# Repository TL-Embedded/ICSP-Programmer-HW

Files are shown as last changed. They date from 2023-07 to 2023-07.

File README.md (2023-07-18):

# ICSP-Programmer-HW

This is a ICSP programming board for AVR targets.

The processor onboard is an ATMEGA8A, and can be programmed using another ICSP-Programmer.

# Connector

The connector is laid out as per a standard Arduino ICSP programmer, so this can to program AVR Arduinos via IDC ribbon cable. This can also be combined with a TC2030 cable for a tag connect solution.

The ICSP connector is laid out as follows:

| Function | Pin # | Pin # | Function |
| --- | ----- | ----- | --- |
| MISO | 1 | 2 | VCC |
| SCK | 3 | 4 | MOSI |
| NRST | 5 | 6 | GND |

# Target VCC

The programmer powered via 5V from USB, but does **not** power the target by default. The `VCC` pin is used for voltage reference. The target voltage may be anywhere between 1.8V and 5.5V.

The labeled `VCC` pin can be used to inject voltage to the target. Alternately the jumper `JP1` can be shorted to tie `VCC` to USB 5V.

# USB

The USB C connector operates in USB 2.0 legacy mode. A FTDI `FT230QX` chip provides a serial port interface.

Drivers for the FTDI chip can be found [here](https://ftdichip.com/drivers/).

# Firmware

The firmware for this PCB is [ICSP-FW.hex](./firmware/ICSP-FW.hex).
See the usage section for an example of programming a ICSP programmer from another programmer.

Note: To Program a ICSP programmer, its target `VCC` must *not* be powered. Ensure that `JP1` is open, and no power is provided via the `VCC` pin or ICSP connector.

# Usage

The windows executable version of [avrdude](https://github.com/avrdudes/avrdude) is included in this repo to flash a target.

You will need to substitute your serial port and target information.

An example for flashing the ICSP firmware is below:
```sh
# Verify the target is connected.
.\avrdude.exe -C "avrdude.conf" -c avrisp -P COM3 -b 115200 -p ATMEGA8

# Configure the target fuses.
# This is required to set the oscillator config
.\avrdude.exe -C "avrdude.conf" -c avrisp -P COM3 -b 115200 -p ATMEGA8 -U lfuse:w:0xbe:m -U hfuse:w:0xd9:m

# Flash the target with 'ICSP-FW.hex'
.\avrdude.exe -C "avrdude.conf" -c avrisp -P COM3 -b 115200 -p ATMEGA8 -U flash:w:ICSP-FW.hex:i
```

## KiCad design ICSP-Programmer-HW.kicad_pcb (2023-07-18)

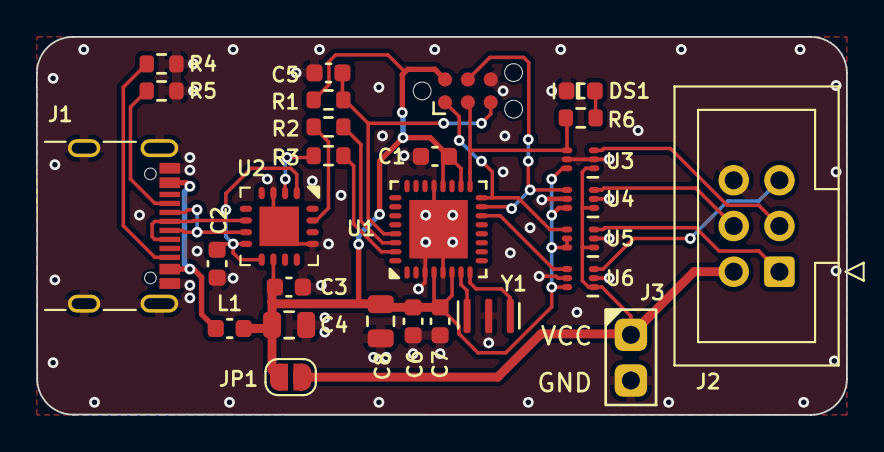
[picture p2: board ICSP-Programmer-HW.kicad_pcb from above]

Board: 2 copper layers, 45.0 x 21.0 mm, 28 parts (0 on the bottom side), 25 nets.

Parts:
C1, C2, C3, C5, C6, C7: 100n; C_0603
C4, C8: 10u; C_0805
DS1: LED_GRN; DS_0603
J1: USB4105-GF-A-060; USB_C_USB4105-GF-A-060
J2: 61200621621; IDC-Header_2x03_P2.54mm_Vertical
J3: Pins_2.54_1x2; Pins-2.54-1x2
JP1: SolderJumper2; SolderJumper-2_P1.3mm_Open_RoundedPad1.0x1.5mm
L1: 600R; FB_0603
N1: TC2030_NL_SWD; TagConnect_TC2030_NL
R1: 10K; R_0603
R2, R3: 1K; R_0603
R4, R5: 5K1; R_0603
R6: 470R; R_0603
U1: ATMEGA8A-MU; QFN32_05_5x5_EP
U2: FT230XQ; QFN16_065_4x4_EP
U3, U4, U5, U6: 74LVC1T45Z6; SOT563
Y1: CSTNE16M0V530000R0; Oscillator_SMD3_3.2x1.3

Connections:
+3.3V: C2.1, U2.1 (VCCIO), U2.8 (3V3OUT), U2.9 (NRST)
+5V: C1.1, C3.1, C4.1, C6.1, C7.1, C8.1, JP1.1 (A), L1.2, N1.2, R1.1, U1.4 (VCC), U1.6 (VCC), U1.18 (AVCC), U1.20 (AREF), U2.10 (VCC), U3.6 (VCCB), U4.6 (VCCB), U5.5 (DIR), U5.6 (VCCB), U6.6 (VCCB)
/MCU/ICSP_MISO: N1.1, U1.16 (PB4/MISO), U5.4 (B)
/MCU/ICSP_MOSI: N1.4, U1.15 (PB3/MOSI), U4.4 (B)
/MCU/ICSP_NRST: C5.1, N1.5, R1.2, U1.29 (NRST/PC5)
/MCU/ICSP_SCK: N1.3, R6.1, U1.17 (SCK/PB5), U3.4 (B)
/MCU/RX: R2.2, U1.30 (RXD/PD0)
/MCU/TARGET_NRST: U1.14 (PB2), U6.4 (B)
/MCU/TX: R3.1, U1.31 (TXD/PD1)
/Target/TARGET_MISO: J2.1, U5.3 (A)
/Target/TARGET_MOSI: J2.4, U4.3 (A)
/Target/TARGET_NRST: J2.5, U6.3 (A)
/Target/TARGET_SCK: J2.3, U3.3 (A)
/Target/TARGET_VCC: J2.2, J3.1, JP1.2 (B), U3.1 (VCCA), U4.1 (VCCA), U5.1 (VCCA), U6.1 (VCCA)
/USB/USB_DM: J1.A7 (D-), J1.B7 (D-), U2.7 (USBDM)
/USB/USB_DP: J1.A6 (D+), J1.B6 (D+), U2.6 (USBDP)
GND: C1.2, C2.2, C3.2, C4.2, C5.2, C6.2, C7.2, C8.2, DS1.1 (K), J1.A1 (GND), J1.A12 (GND), J1.S (SHIELD), J2.6, J3.2, N1.6, R4.2, R5.2, U1.3 (GND), U1.5 (GND), U1.21 (GND), U1.33 (EP), U2.3 (GND), U2.13 (GND), U2.17 (GND), U3.2 (GND), U3.5 (DIR), U4.2 (GND), U4.5 (DIR), U5.2 (GND), U6.2 (GND), U6.5 (DIR), Y1.2
unnamed: DS1.2 (A), R6.2
unnamed: J1.A5 (CC1), R5.1
unnamed: J1.B5 (CC2), R4.1
unnamed: J1.A4 (VBUS), J1.A9 (VBUS), L1.1
unnamed: U1.7 (PB7/XTAL1), Y1.1
unnamed: U1.8 (PB7/XTAL2), Y1.3
unnamed: R3.2, U2.2 (RXD)
unnamed: R2.1, U2.15 (TXD)

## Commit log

2023-07-04 Do PCB
    [ICSP-Programmer-HW.kicad_pcb, mcu.kicad_sch, target.kicad_sch]
2023-07-04 Update readme
    Add jumper to tie 5V to VCC
    [ICSP-Programmer-HW.kicad_pcb, target.kicad_sch]
2023-07-18 Fix direction issue on MISO/MOSI
    [ICSP-Programmer-HW.kicad_pcb, ICSP-Programmer-HW.kicad_sch, mcu.kicad_sch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]
2023-07-18 PCB version to 1.1
    [ICSP-Programmer-HW.kicad_pcb]
